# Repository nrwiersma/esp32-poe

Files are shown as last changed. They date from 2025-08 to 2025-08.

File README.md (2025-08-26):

# ESP32 PoE




`ESP32 PoE` is an ESP32 dev-kit with a W5500 LAN with PoE.

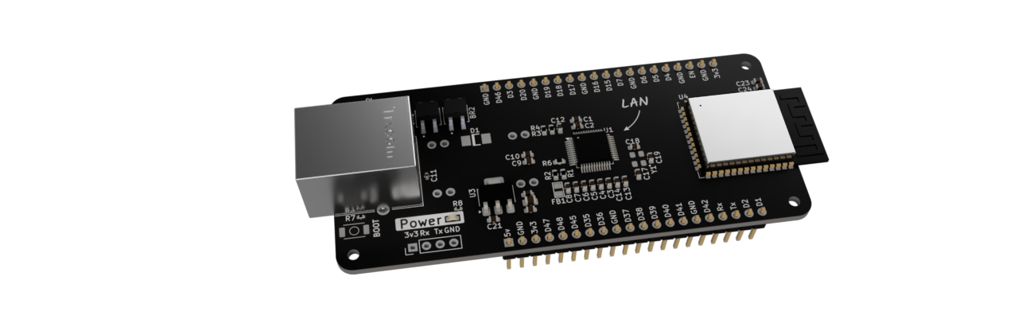
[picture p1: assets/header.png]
board image


Features:

* W5500 Ethernet
* PoE (Power over Ethernet) 802.3af 7W
* ESP32 S3 WROOM-1

## Tasmota Configuration

To configure Tasmota for the ESP32 PoE board, you can use the following template:

```
{"NAME":"ESP32PoE","GPIO":[0,1,1,1,1,1,1,1,0,5536,5600,704,672,736,5568,1,1,1,1,1,1,0,0,0,1,1,1,1,1,1,1,1,1,1,1,1,1,1],"FLAG":0,"BASE":1}
```

and set the `EthType` option to `8`.

Optionally you can disable WiFi by setting `Wifi` option to `0` in the consoleSt.

## BOM

See the [Interactive BOM](https://htmlpreview.github.io/?https://github.com/nrwiersma/esp32-poe/blob/main/bom/ibom.html) [(provided by InteractiveHtmlBom)
](https://github.com/openscopeproject/InteractiveHtmlBom).

## Why

When dealing with IoT devices, you often want to place them in locations where power outlets are not readily available. 
Power over Ethernet (PoE) allows you to power devices through the same Ethernet cable used for data transmission, 
simplifying installation and reducing cable clutter. It also allows for centralized power management, 
making it easier to monitor and control the power supply to multiple devices.

## Changelog

#### v0.1.0

* Initial schematic and board

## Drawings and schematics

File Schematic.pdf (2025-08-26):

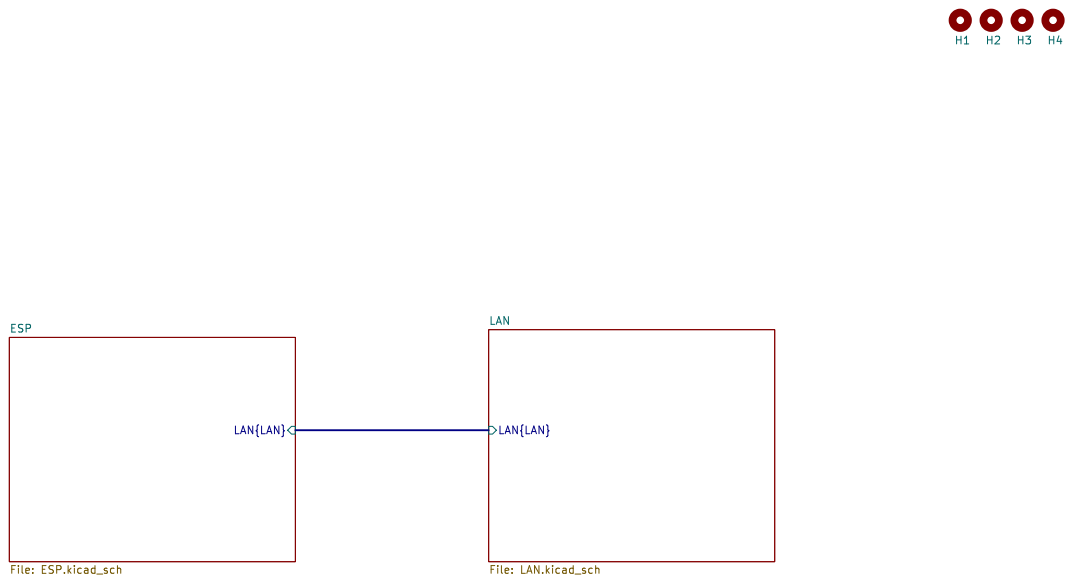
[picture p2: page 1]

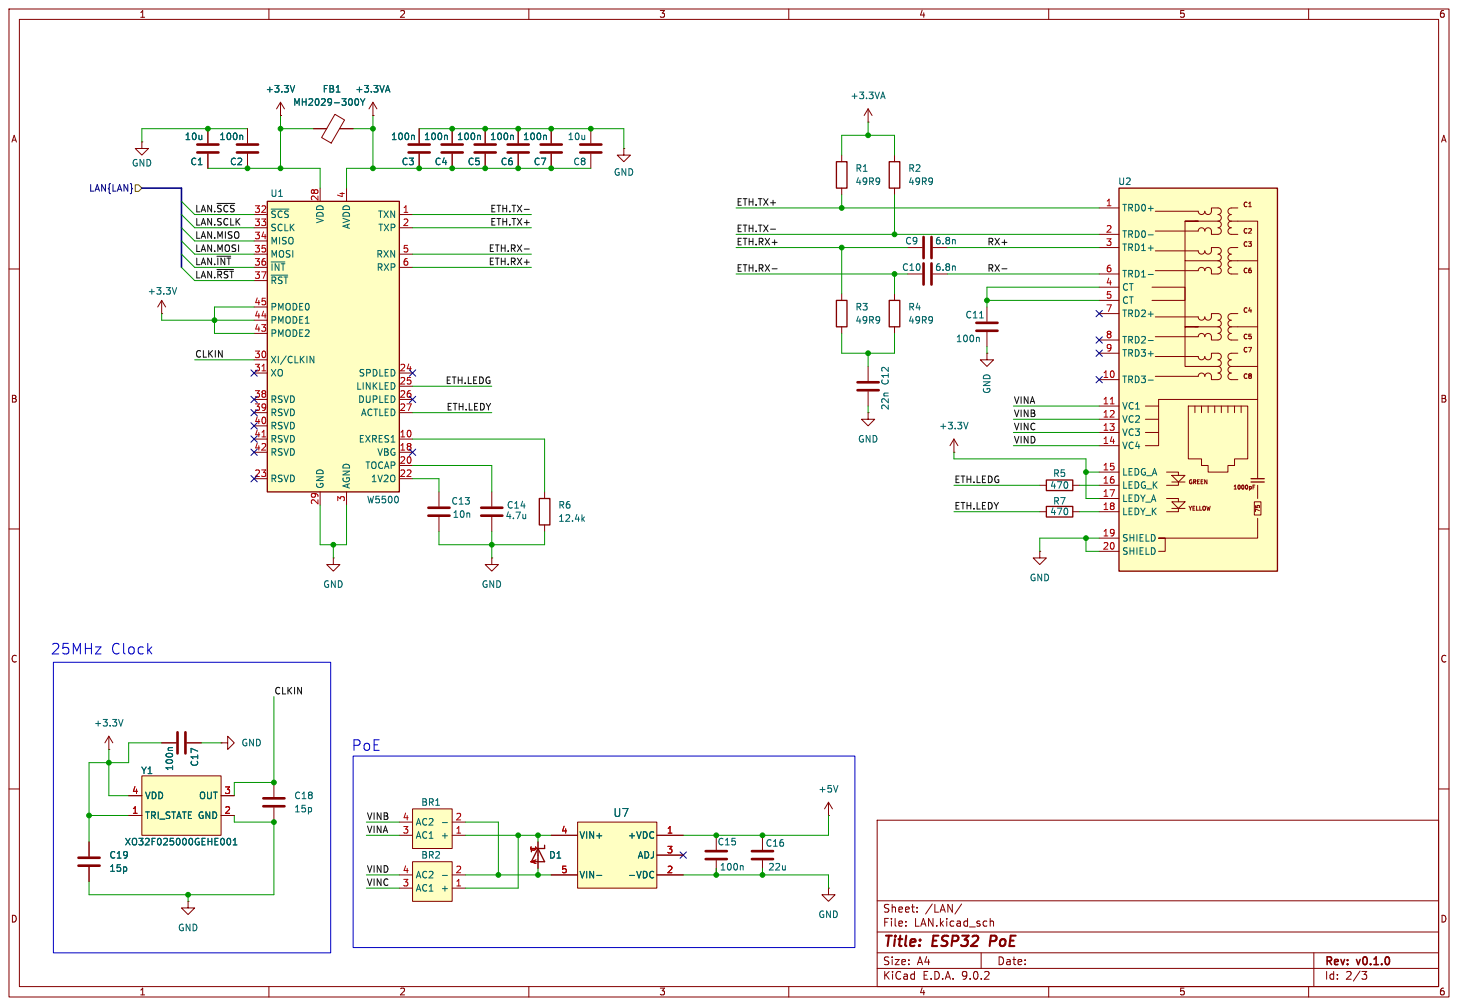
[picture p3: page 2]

LAN.~{SCS} LAN.SCLK
LAN.MOSI LAN.MISO

3 TXN 1 TXP 2 RXN 5 RXP 6 SPDLED 24

File: LAN.kicad_sch Sheet: /LAN/ +5V

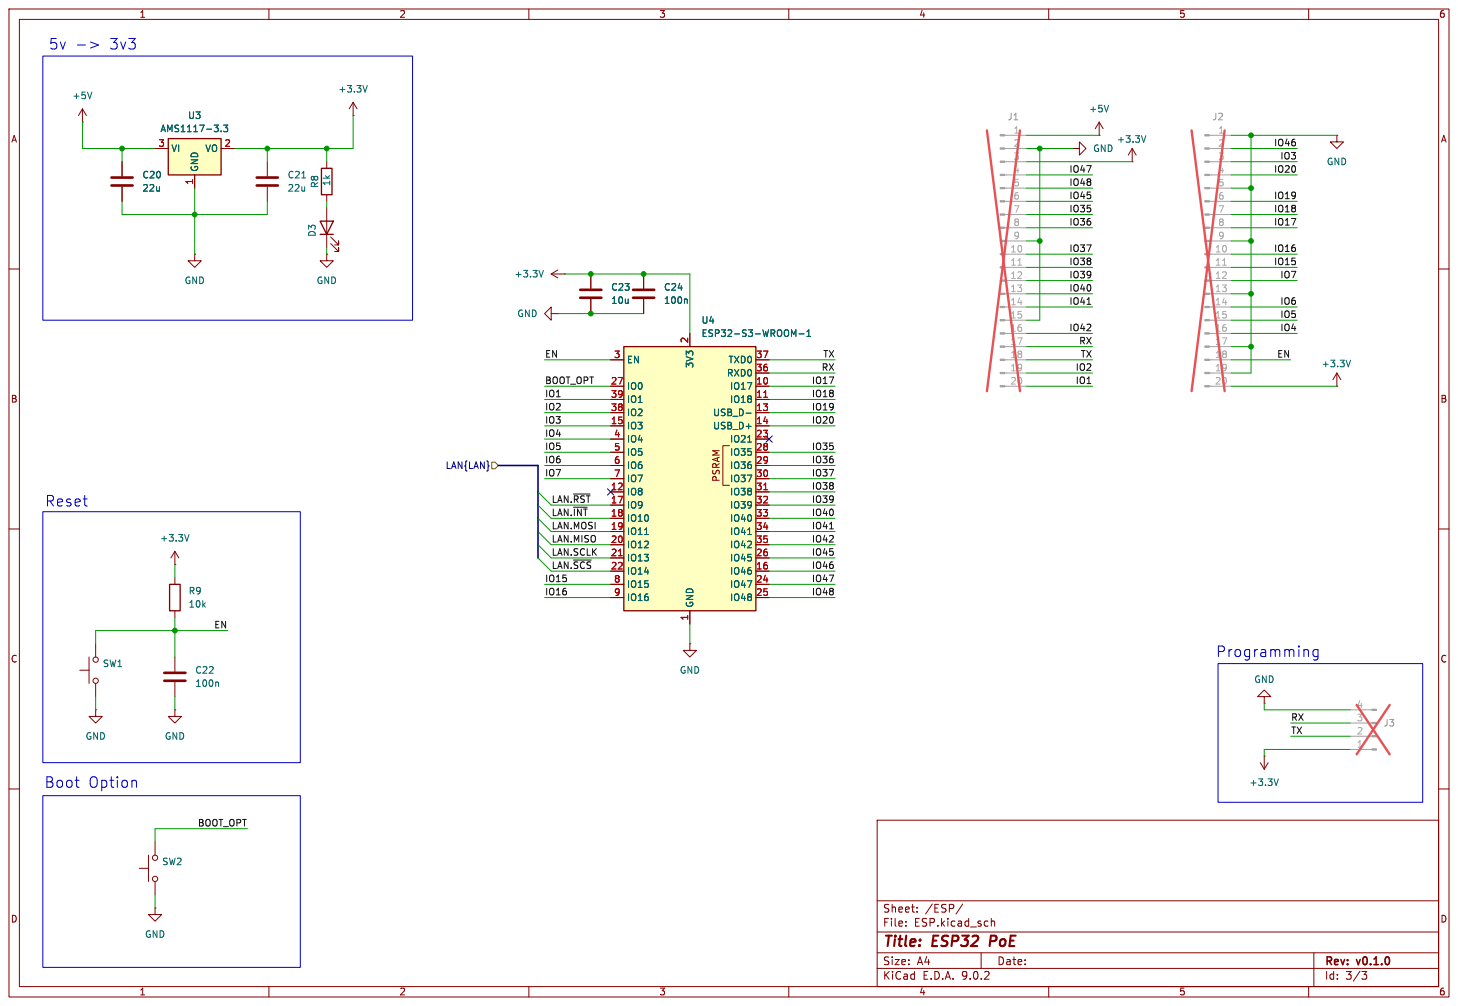
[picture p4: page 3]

LAN.~{RST}
LAN.~{INT}
LAN.MOSI LAN.MISO

File: ESP.kicad_sch Sheet: /ESP/ GND

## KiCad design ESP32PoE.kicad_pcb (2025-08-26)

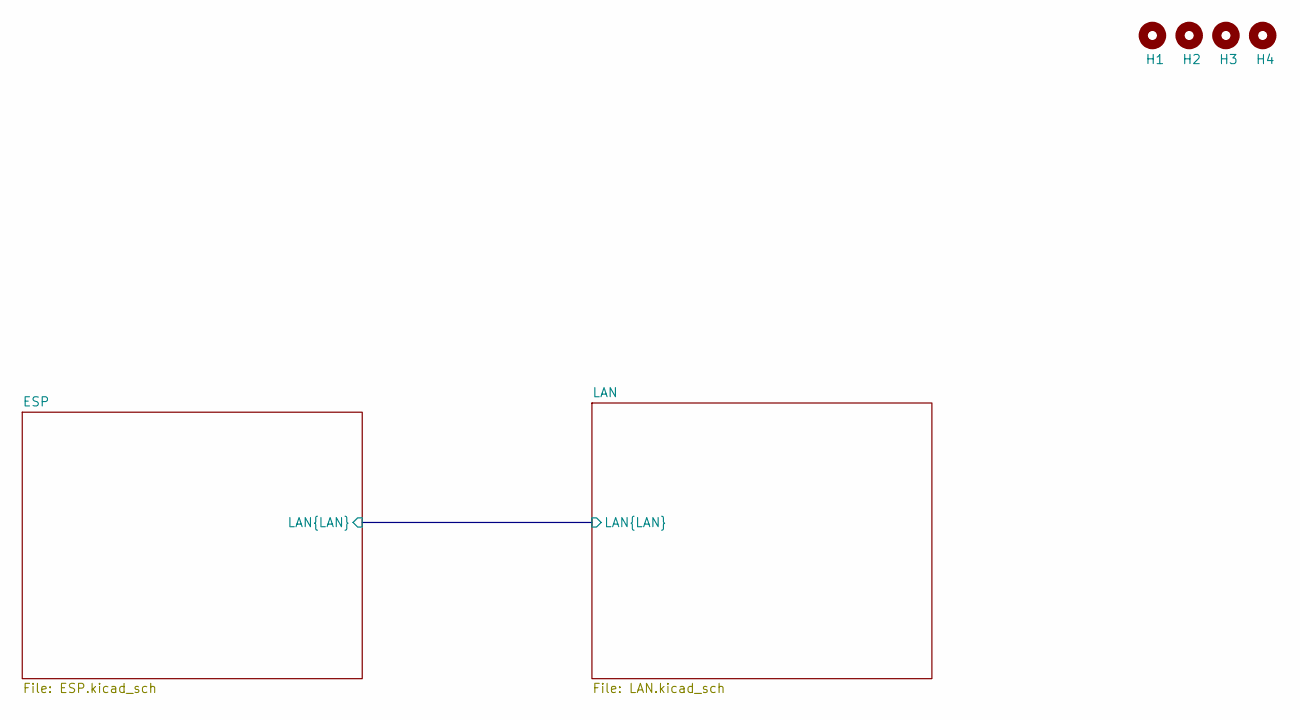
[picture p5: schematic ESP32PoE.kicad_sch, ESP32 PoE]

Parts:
H1, H2, H3, H4: MountingHole; MountingHole_2.2mm_M2

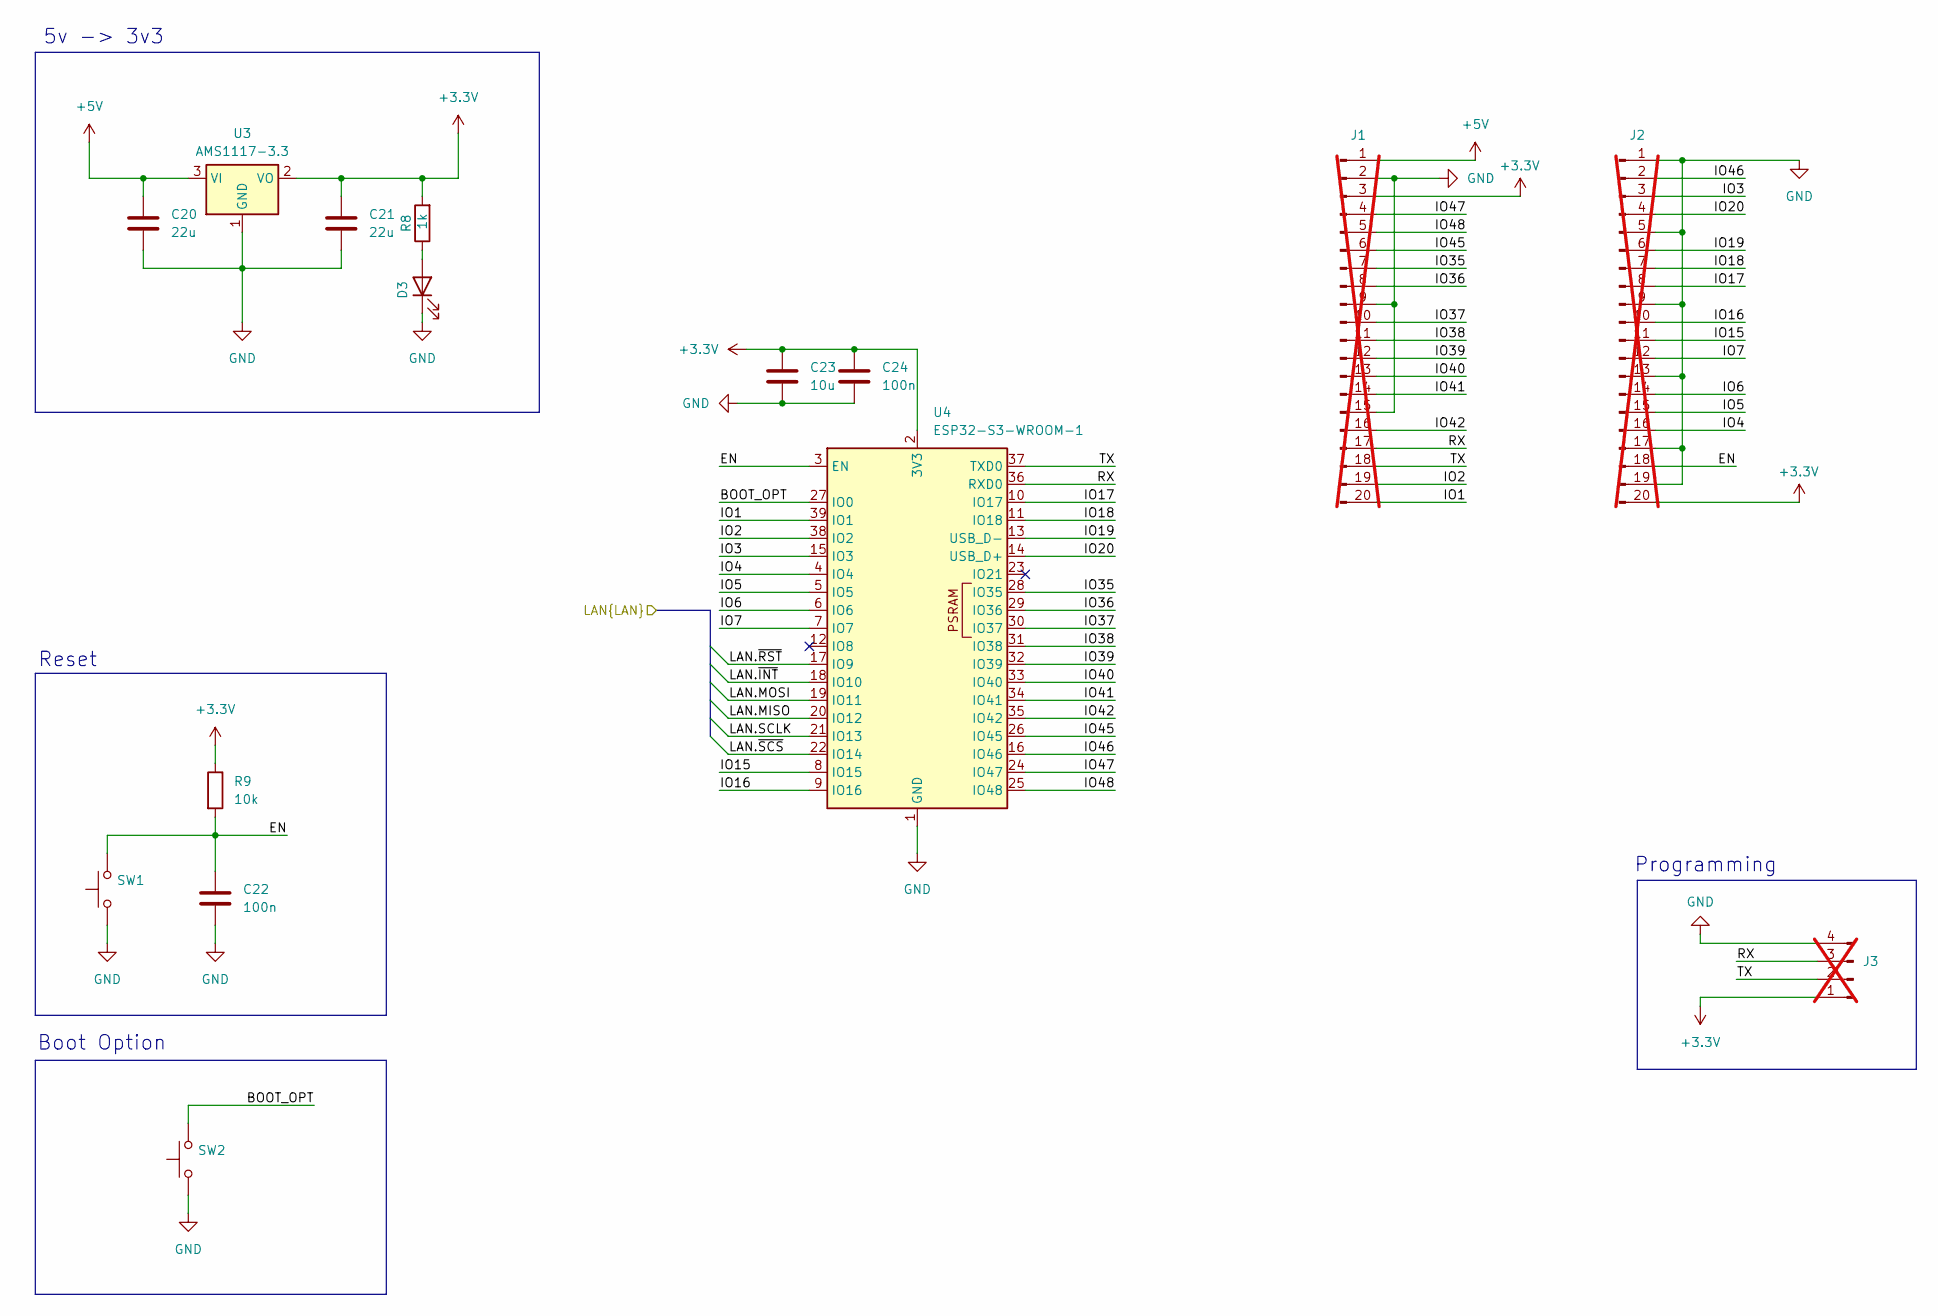
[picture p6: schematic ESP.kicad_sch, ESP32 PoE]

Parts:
C20, C21: 22u; C_0603_1608Metric; MPN CL10A226MQ8NRNC; JLCPCB Part # C59461
C22, C24: 100n; C_0603_1608Metric; MPN CL10B104KB8NNNC; JLCPCB Part # C1591
C23: 10u; C_0603_1608Metric; MPN CL10A106MA8NRNC; JLCPCB Part # C96446
D3: LED; LED_0603_1608Metric; MPN LTST-C191KRKT; JLCPCB Part # C125099
J1, J2: Conn_01x20_Pin; PinHeader_1x20_P2.54mm_Vertical; not fitted
J3: Conn_01x04_Pin; PinHeader_1x04_P2.54mm_Vertical; not fitted
R8: 1k; R_0402_1005Metric; MPN RK73H1ETTP1001F; JLCPCB Part # C131360
R9: 10k; R_0603_1608Metric; MPN CR0603AFX-1002EAS; JLCPCB Part # C2091877
SW1, SW2: SW_Push; SMD,3x4mm; MPN TS-1088R-02026; JLCPCB Part # C455280
U3: AMS1117-3.3; SOT-223-3_TabPin2; MPN AMS1117-3.3; JLCPCB Part # C347222
U4: ESP32-S3-WROOM-1; MPN ESP32-S3-WROOM-1-N4; JLCPCB Part # C2913197

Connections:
+3.3V: C21.1, C23.1, C24.1, J1.3, J2.20, J3.1, R8.2, R9.1, U3.2 (VO), U4.2 (3V3); also elsewhere on the board
+5V: C20.1, J1.1, U3.3 (VI); also elsewhere on the board
/ESP/BOOT_OPT: SW2.2, U4.27 (IO0)
/ESP/EN: C22.1, J2.18, R9.2, SW1.2, U4.3 (EN)
/ESP/IO1: J1.20, U4.39 (IO1)
/ESP/IO2: J1.19, U4.38 (IO2)
/ESP/IO3: J2.3, U4.15 (IO3)
/ESP/IO4: J2.16, U4.4 (IO4)
/ESP/IO5: J2.15, U4.5 (IO5)
/ESP/IO6: J2.14, U4.6 (IO6)
/ESP/IO7: J2.12, U4.7 (IO7)
/ESP/IO15: J2.11, U4.8 (IO15)
/ESP/IO16: J2.10, U4.9 (IO16)
/ESP/IO17: J2.8, U4.10 (IO17)
/ESP/IO18: J2.7, U4.11 (IO18)
/ESP/IO19: J2.6, U4.13 (USB_D-)
/ESP/IO20: J2.4, U4.14 (USB_D+)
/ESP/IO35: J1.7, U4.28 (IO35)
/ESP/IO36: J1.8, U4.29 (IO36)
/ESP/IO37: J1.10, U4.30 (IO37)
/ESP/IO38: J1.11, U4.31 (IO38)
/ESP/IO39: J1.12, U4.32 (IO39)
/ESP/IO40: J1.13, U4.33 (IO40)
/ESP/IO41: J1.14, U4.34 (IO41)
/ESP/IO42: J1.16, U4.35 (IO42)
/ESP/IO45: J1.6, U4.26 (IO45)
/ESP/IO46: J2.2, U4.16 (IO46)
/ESP/IO47: J1.4, U4.24 (IO47)
/ESP/IO48: J1.5, U4.25 (IO48)
/ESP/LAN.MISO: U4.20 (IO12); also elsewhere on the board
/ESP/LAN.MOSI: U4.19 (IO11); also elsewhere on the board
/ESP/LAN.SCLK: U4.21 (IO13); also elsewhere on the board
/ESP/LAN.~INT: U4.18 (IO10); also elsewhere on the board
/ESP/LAN.~RST: U4.17 (IO9); also elsewhere on the board
/ESP/LAN.~SCS: U4.22 (IO14); also elsewhere on the board
/ESP/RX: J1.17, J3.3, U4.36 (RXD0)
/ESP/TX: J1.18, J3.2, U4.37 (TXD0)
GND: C20.2, C21.2, C22.2, C23.2, C24.2, D3.1 (K), J1.2, J1.9, J1.15, J2.1, J2.5, J2.9, J2.13, J2.17, J2.19, J3.4, SW1.1, SW2.1, U3.1 (GND), U4.1 (GND), U4.40 (GND), U4.41 (GND); also elsewhere on the board
unnamed: D3.2 (A), R8.1

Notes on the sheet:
Reset
5v -> 3v3
Programming
Boot Option

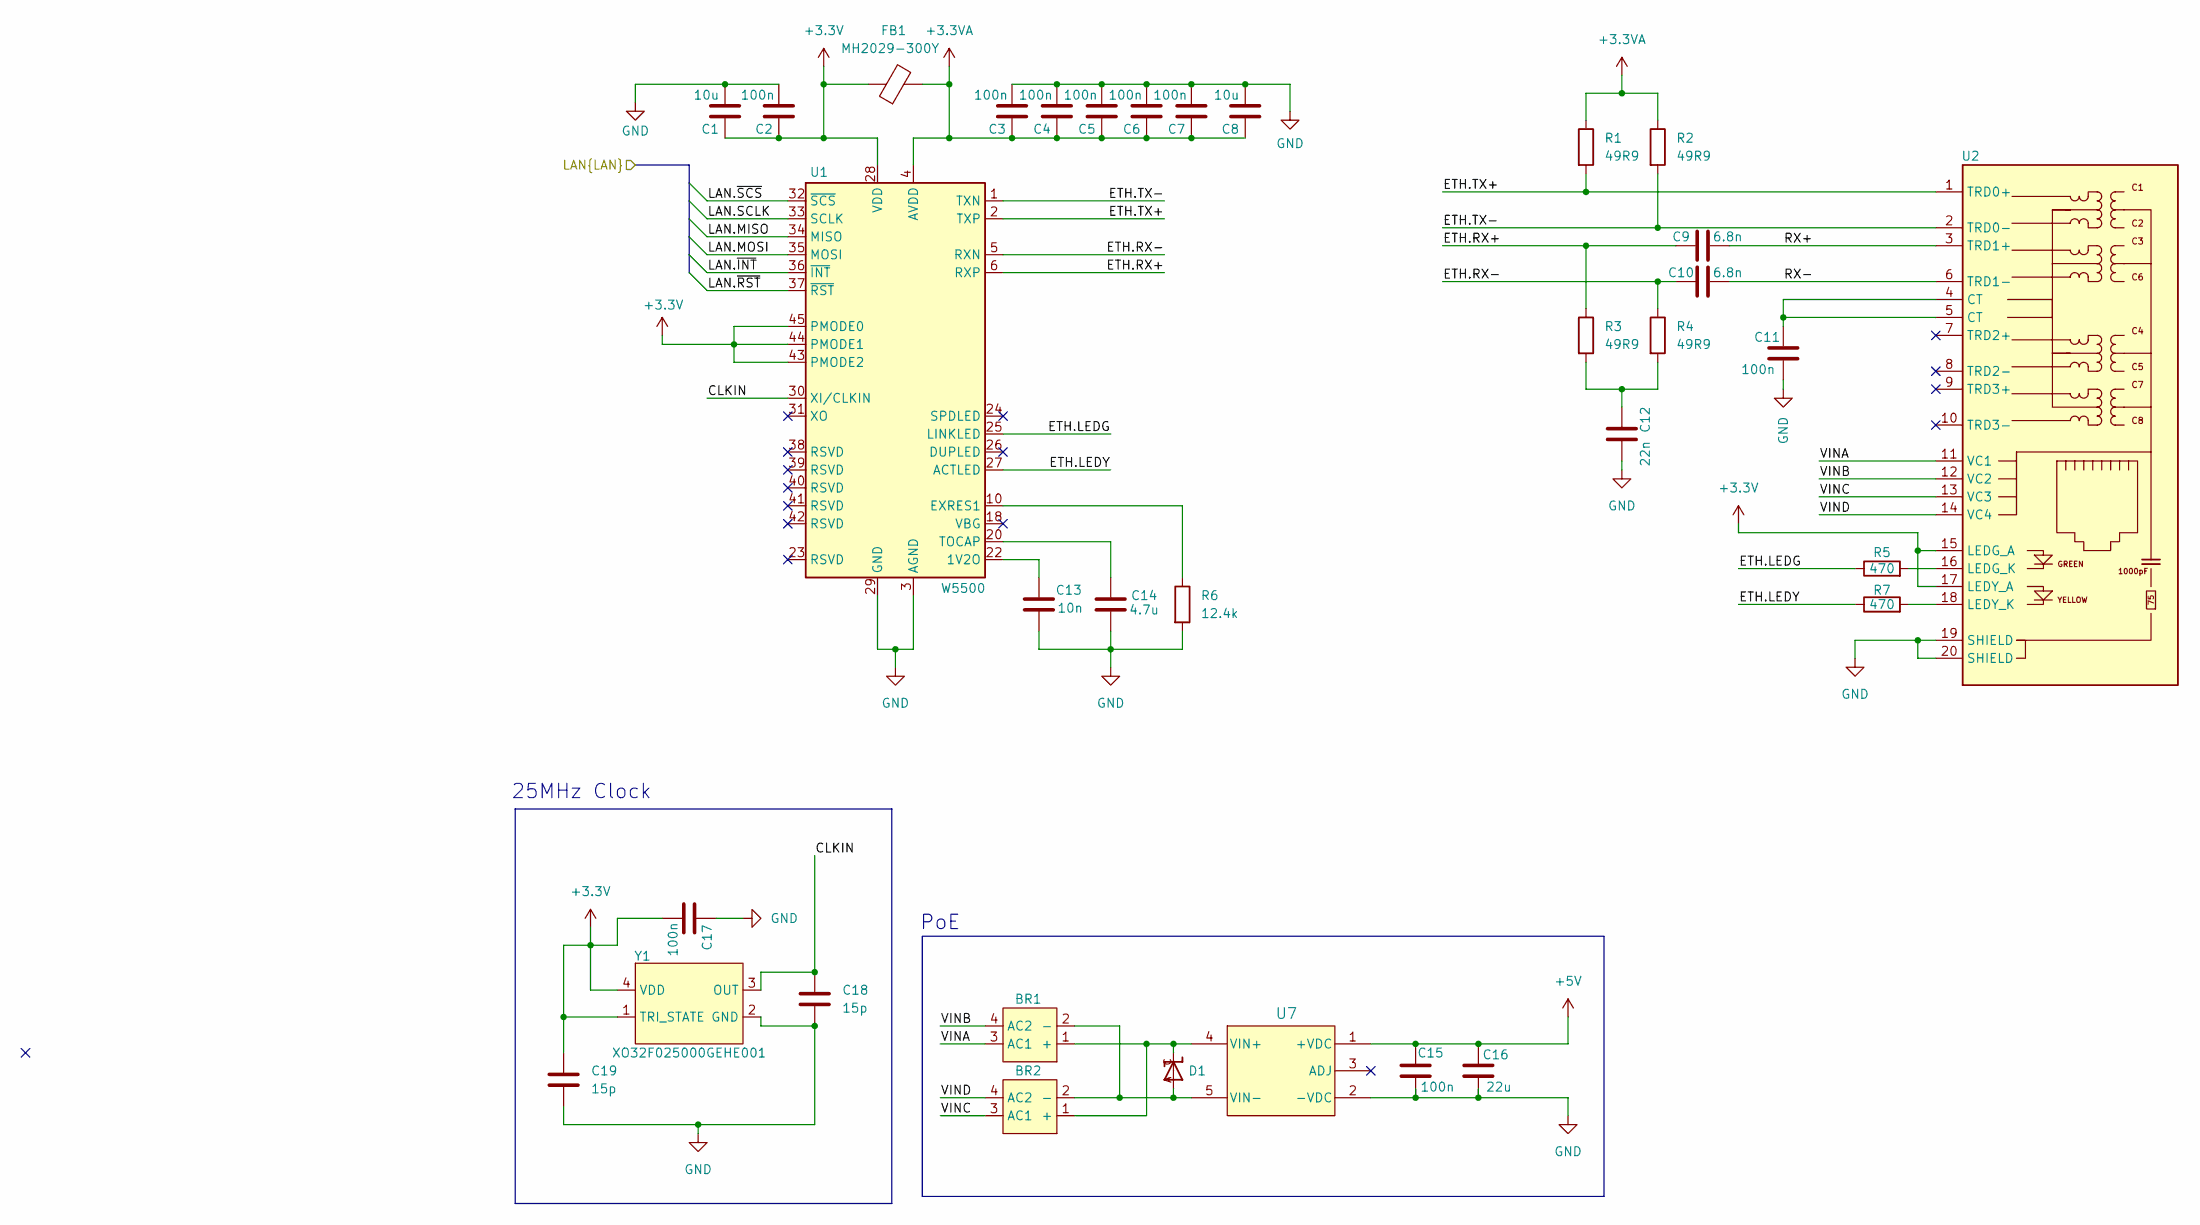
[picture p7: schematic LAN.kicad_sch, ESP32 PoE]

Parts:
BR1, BR2: CDBHM1100L-G; MPN CDBHM1100L-G; JLCPCB Part # C17288728
C1, C8: 10u; C_0603_1608Metric; MPN CL10A106MA8NRNC; JLCPCB Part # C96446
C2, C3, C4, C5, C6, C7, C15, C17: 100n; C_0603_1608Metric; MPN CL10B104KB8NNNC; JLCPCB Part # C1591
C9, C10: 6.8n; C_0603_1608Metric; MPN CC0603KRX7R0BB682; JLCPCB Part # C576854
C11: 100n; C_0402_1005Metric; MPN CL05B104KO5NNNC; JLCPCB Part # C1525
C12: 22n; C_0603_1608Metric; MPN CL10A225KA8NNNC; JLCPCB Part # C57895
C13: 10n; C_0603_1608Metric; MPN CL10B103KB8NNNC; JLCPCB Part # C1589
C14: 4.7u; C_0603_1608Metric; MPN CL10A475KP8NNNC; JLCPCB Part # C1705
C16: 22u; C_0805_2012Metric; MPN CL21A226KPCLRNC; JLCPCB Part # C318688
C18, C19: 15p; C_0603_1608Metric; MPN CL10C150JB8NNNC; JLCPCB Part # C1644
D1: SMAJ58A; MPN SMAJ58A; JLCPCB Part # C151246
FB1: MH2029-300Y; L0805; MPN MH2029-300Y; JLCPCB Part # C840593
R1, R2, R3, R4: 49R9; R_0603_1608Metric; MPN RC0603FR-0749R9L; JLCPCB Part # C114625
R5, R7: 470; R_0402_1005Metric; MPN RC0402FR-7W470RL; JLCPCB Part # C606172
R6: 12.4k; R_0603_1608Metric; MPN RC0603FR-0712K4L; JLCPCB Part # C137798
U1: W5500; LQFP-48_7x7mm_P0.5mm; MPN W5500; JLCPCB Part # C32843
U2: MagJack-A70-112-331N126; TRJG0926HENL; MPN DGUK111Q334AB2A2DP057; JLCPCB Part # C19725175
U7: AG9905LP; MPN AG9905LP
Y1: XO32F025000GEHE001; SMD3225-4P; MPN XO32F025000GEHE001; JLCPCB Part # C20607963

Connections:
+3.3V: C1.1, C2.1, C17.2, C19.2, FB1.1, U1.28 (VDD), U1.43 (PMODE2), U1.44 (PMODE1), U1.45 (PMODE0), U2.15 (LEDG_A), U2.17 (LEDY_A), Y1.1 (TRI_STATE), Y1.4 (VDD); also elsewhere on the board
+3.3VA: C3.1, C4.1, C5.1, C6.1, C7.1, C8.1, FB1.2, R1.1, R2.1, U1.4 (AVDD), U1.8 (AVDD), U1.11 (AVDD), U1.15 (AVDD), U1.17 (AVDD), U1.21 (AVDD)
+5V: C15.2, C16.1, U7.1 (+VDC); also elsewhere on the board
/ESP/LAN.MISO: U1.34 (MISO); also elsewhere on the board
/ESP/LAN.MOSI: U1.35 (MOSI); also elsewhere on the board
/ESP/LAN.SCLK: U1.33 (SCLK); also elsewhere on the board
/ESP/LAN.~INT: U1.36 (~INT); also elsewhere on the board
/ESP/LAN.~RST: U1.37 (~RST); also elsewhere on the board
/ESP/LAN.~SCS: U1.32 (~SCS); also elsewhere on the board
/LAN/CLKIN: C18.1, U1.30 (XI/CLKIN), Y1.3 (OUT)
/LAN/ETH.LEDG: R5.1, U1.25 (LINKLED)
/LAN/ETH.LEDY: R7.1, U1.27 (ACTLED)
/LAN/ETH.RX+: C9.1, R3.1, U1.6 (RXP)
/LAN/ETH.RX-: C10.1, R4.1, U1.5 (RXN)
/LAN/ETH.TX+: R1.2, U1.2 (TXP), U2.1 (TRD0+)
/LAN/ETH.TX-: R2.2, U1.1 (TXN), U2.2 (TRD0-)
/LAN/RX+: C9.2, U2.3 (TRD1+)
/LAN/RX-: C10.2, U2.6 (TRD1-)
/LAN/VINA: BR1.3 (AC1), U2.11 (VC1)
/LAN/VINB: BR1.4 (AC2), U2.12 (VC2)
/LAN/VINC: BR2.3 (AC1), U2.13 (VC3)
/LAN/VIND: BR2.4 (AC2), U2.14 (VC4)
GND: C1.2, C2.2, C3.2, C4.2, C5.2, C6.2, C7.2, C8.2, C11.2, C12.2, C13.2, C14.2, C15.1, C16.2, C17.1, C18.2, C19.1, R6.2, U1.3 (AGND), U1.9 (AGND), U1.14 (AGND), U1.16 (AGND), U1.19 (AGND), U1.29 (GND), U1.48 (AGND), U2.19 (SHIELD), U2.20 (SHIELD), U7.2 (-VDC), Y1.2 (GND); also elsewhere on the board
unnamed: BR1.1 (+), BR2.1 (+), D1.C, U7.4 (VIN+)
unnamed: BR1.2 (-), BR2.2 (-), D1.A, U7.5 (VIN-)
unnamed: C11.1, U2.4 (CT), U2.5 (CT)
unnamed: C12.1, R3.2, R4.2
unnamed: C13.1, U1.22 (1V2O)
unnamed: R6.1, U1.10 (EXRES1)
unnamed: C14.1, U1.20 (TOCAP)
unnamed: R5.2, U2.16 (LEDG_K)
unnamed: R7.2, U2.18 (LEDY_K)

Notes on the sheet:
PoE
25MHz Clock

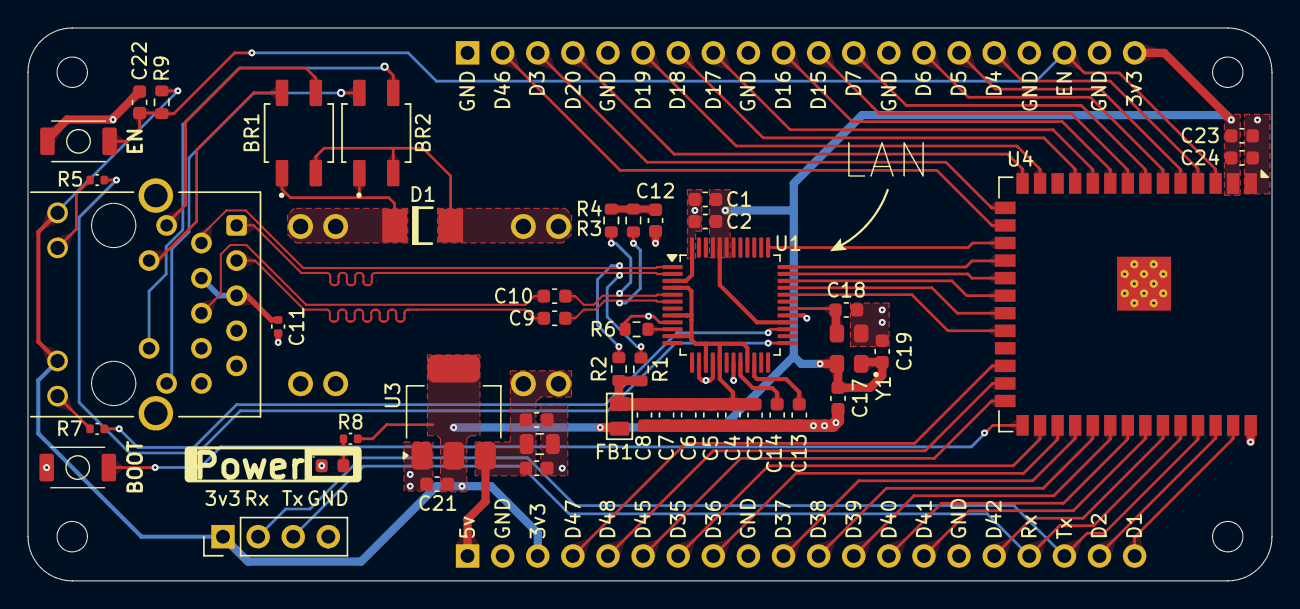
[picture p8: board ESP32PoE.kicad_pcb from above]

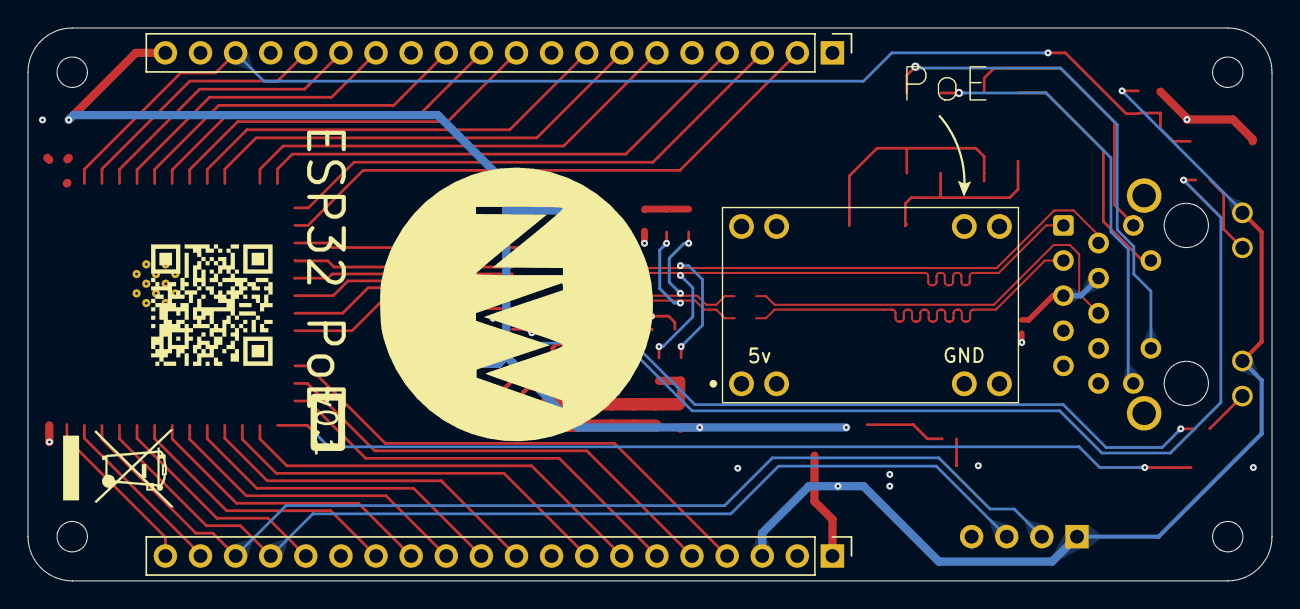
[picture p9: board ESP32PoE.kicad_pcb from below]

Board: 4 copper layers, 90.0 x 40.0 mm, 55 parts (5 on the bottom side), 62 nets.

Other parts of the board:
SS1: LOGO; Logo
SS3: WEEE-Logo_5.6x8mm_SilkScreen

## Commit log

2025-07-24 feat: initial board (#1)
    [ESP.kicad_sch, ESP32PoE.kicad_pcb, ESP32PoE.kicad_sch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]
2025-08-26 chore: add README (#2)
    [ESP.kicad_sch, ESP32PoE.kicad_pcb, ESP32PoE.kicad_sch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]

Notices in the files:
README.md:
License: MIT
